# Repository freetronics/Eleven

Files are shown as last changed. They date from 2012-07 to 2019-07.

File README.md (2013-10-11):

Freetronics Eleven R3
=============================
Copyright 2010-2012 Freetronics Pty Ltd  
Freetronics site:  www.freetronics.com  
Freetronics email: info@freetronics.com  

The Eleven is a 100% Arduino Compatible Board, based on the Arduino
Uno reference design, but with improvements and updates for ease of
use, cost and getting started.

Features:

 * Prototyping area
 * LEDs visible on the edge
 * Mini-USB Connector
 * Overlay guide where you need it (both top and bottom)
 * D13 pin works for everything
 * Mounting holes and power pads
 * All connections in the same place

You can view more at our product page at:

  http://www.freetronics.com/eleven

INSTALLATION
------------
The design is saved as an EAGLE project. EAGLE PCB design software is
available from www.cadsoftusa.com free for non-commercial use. To use
this project download it and place the directory containing these files
into the "eagle" directory on your computer. Then open EAGLE and
navigate to Projects -> eagle -> Eleven.

DISTRIBUTION
------------
The specific terms of distribution of this project are governed by the
license referenced below.

LICENSE
-------
This work is licensed under the
Creative Commons Attribution-Share Alike License.  
To view a copy of this license, visit

  http://creativecommons.org/licenses/by-sa/3.0/  
  http://creativecommons.org/licenses/by-sa/3.0/legalcode

or send a letter to

  Creative Commons  
  171 Second Street, Suite 300  
  San Francisco  
  California, 94105  
  USA

The "license" folder within this repository also contains copies of the
licences referenced above.

CREDITS
-------
The Eleven was designed by Marc Alexander (marc@freetronics.com) and
Jonathan Oxer (jon@freetronics.com) inspired by work by the Arduino
team (www.arduino.cc/playground/Main/People) which includes:

 * Massimo Banzi
 * David Cuartielles
 * Tom Igoe
 * Gianluca Martino
 * David A. Mellis

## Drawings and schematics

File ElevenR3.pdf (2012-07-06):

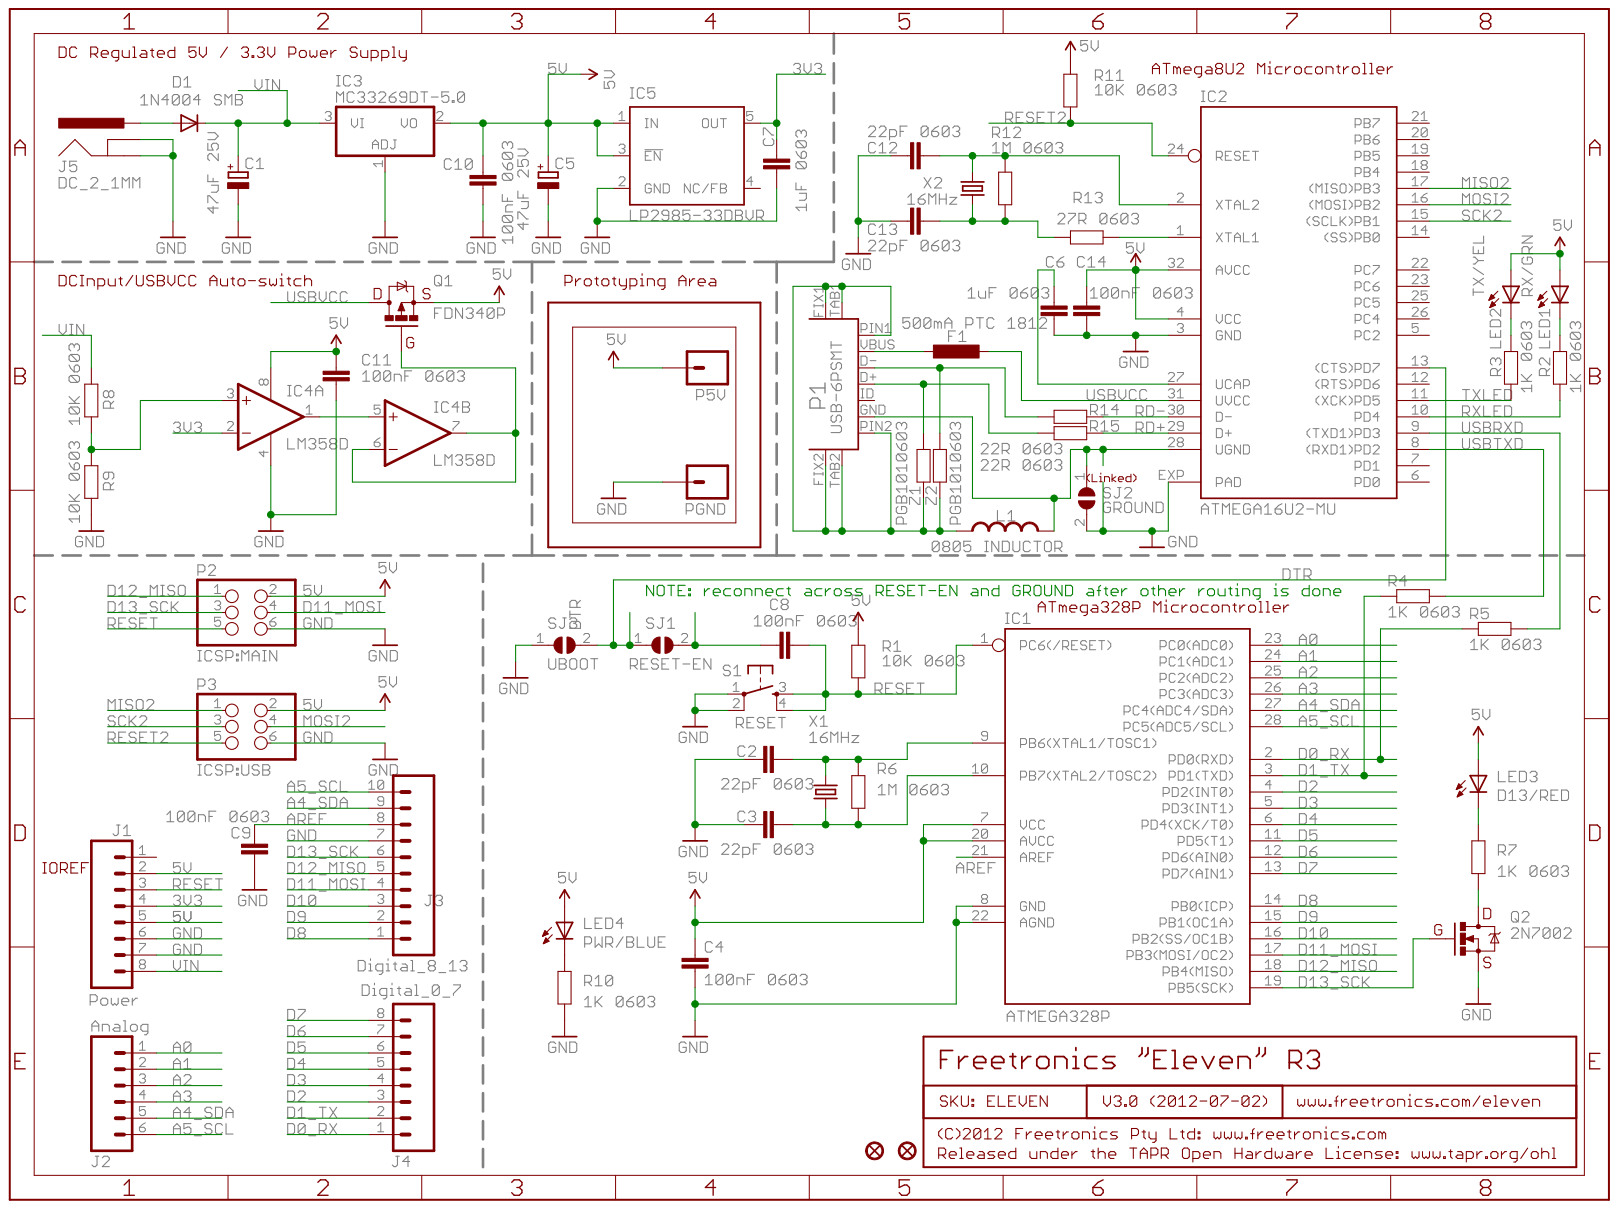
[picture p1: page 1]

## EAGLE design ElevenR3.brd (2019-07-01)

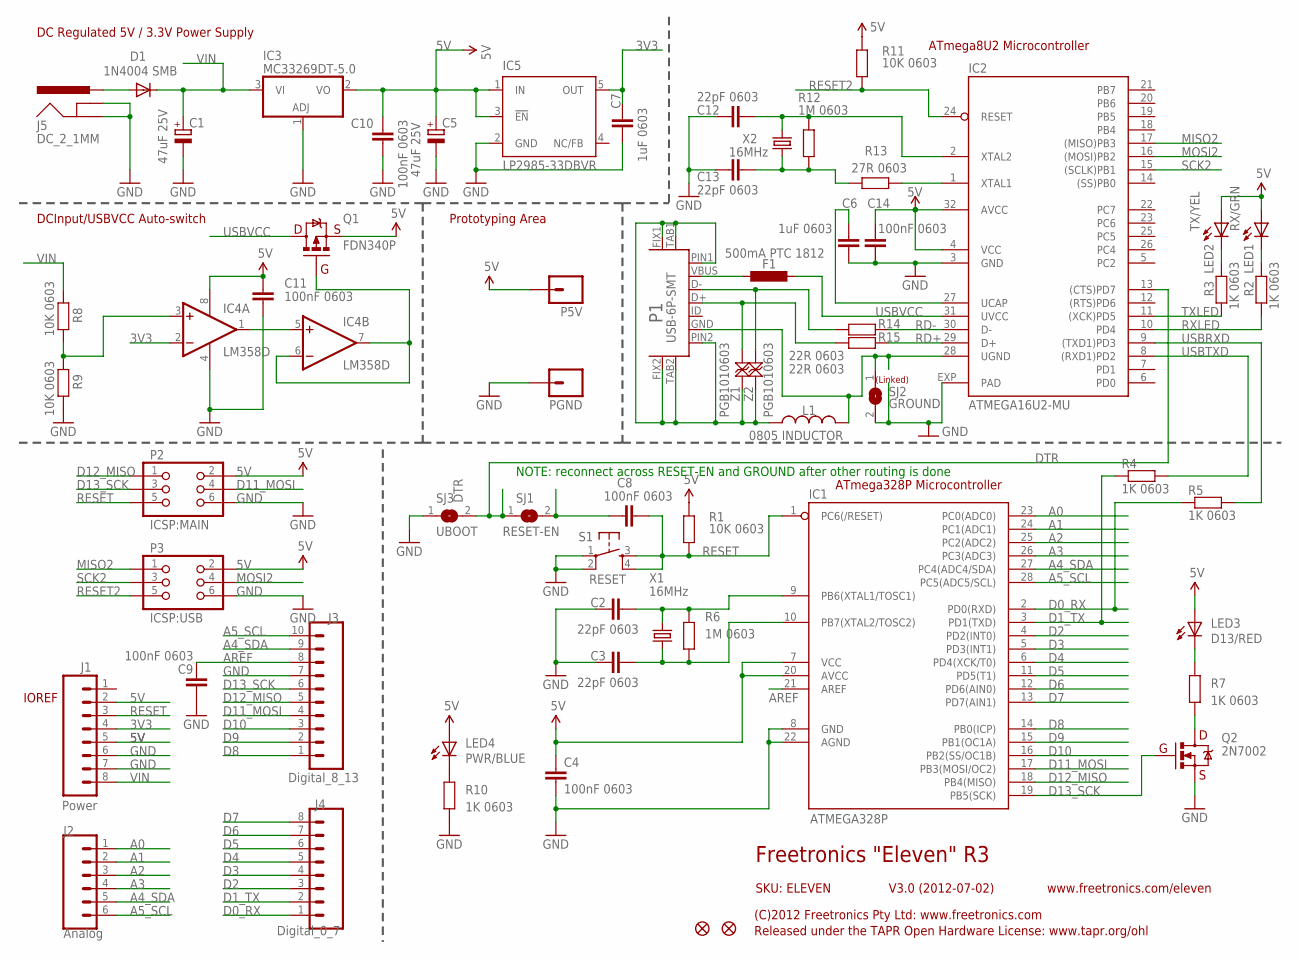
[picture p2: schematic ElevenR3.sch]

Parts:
C1, C5: 47uF 25V; PANASONIC_D
C2, C3, C12, C13: 22pF 0603; C0603
C4, C8, C9, C10, C11, C14: 100nF 0603; C0603
C6, C7: 1uF 0603; C0603
D1: 1N4004 SMB; SMA-DIODE
F1: 500mA PTC 1812; L1812
IC1: ATMEGA328P; DIL28-3
IC2: ATMEGA16U2-MU; ATMEL_QFN32
IC3: MC33269DT-5.0; DPACK
IC4: LM358D; SO08
IC5: LP2985-33DBVR; TEXAS_SOT23-DBV
J1: Power; 1X08-S
J2: Analog; 1X06-S
J3: Digital_8_13; 1X10-S
J4: Digital_0_7; 1X08-S
J5: DC_2_1MM; POWER_JACK_SLOTS
L1: 0805 INDUCTOR; 0805-LARGE
LED1: RX/GRN; LED-0603
LED2: TX/YEL; LED-0603
LED3: D13/RED; LED-0603
LED4: PWR/BLUE; LED-0603
P1: USB-6P-SMT; USB-MICROB-MB05PMXX
P2: ICSP:MAIN; 2X03PTH
P3: ICSP:USB; 2X03PTH
P5V: M01SMD; LUXEON-PAD
PGND: M01SMD; LUXEON-PAD
Q1: FDN340P; SOT23-3
Q2: 2N7002; SOT23-3
R1, R8, R9, R11: 10K 0603; R0603
R2, R3, R4, R5, R7, R10: 1K 0603; R0603
R6, R12: 1M 0603; R0603
R13: 27R 0603; R0603
R14, R15: 22R 0603; R0603
S1: RESET; TACTILE_SMD-6MM
SJ1: RESET-EN; SJ
SJ2: GROUND; SJ
SJ3: UBOOT; SJ
U$5, U$14: FIDUCIAL1X2.5; FIDUCIAL-1X2.5
X1, X2: 16MHz; HC49U-V
Z1, Z2: PGB1010603; TVS0603

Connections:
3V3: C7.2, IC4.2 (-IN), IC5.5 (OUT), J1.4
5V: C4.1, C5.+, C10.1, C11.1, C14.1, IC1.7 (VCC), IC1.20 (AVCC), IC2.4 (VCC), IC2.32 (AVCC), IC3.2 (VO), IC4.8 (V+), IC5.1 (IN), IC5.3 (!EN), J1.2, J1.5, LED1.A, LED2.A, LED3.A, LED4.A, P2.2, P3.2, P5V.P$1, Q1.2 (S), R1.2, R11.2
A0: IC1.23 (PC0(ADC0)), J2.1
A1: IC1.24 (PC1(ADC1)), J2.2
A2: IC1.25 (PC2(ADC2)), J2.3
A3: IC1.26 (PC3(ADC3)), J2.4
A4_SDA: IC1.27 (PC4(ADC4/SDA)), J2.5, J3.9
A5_SCL: IC1.28 (PC5(ADC5/SCL)), J2.6, J3.10
AREF: C9.1, IC1.21 (AREF), J3.8
D0_RX: IC1.2 (PD0(RXD)), J4.1, R5.1
D1_TX: IC1.3 (PD1(TXD)), J4.2, R4.1
D2: IC1.4 (PD2(INT0)), J4.3
D3: IC1.5 (PD3(INT1)), J4.4
D4: IC1.6 (PD4(XCK/T0)), J4.5
D5: IC1.11 (PD5(T1)), J4.6
D6: IC1.12 (PD6(AIN0)), J4.7
D7: IC1.13 (PD7(AIN1)), J4.8
D8: IC1.14 (PB0(ICP)), J3.1
D9: IC1.15 (PB1(OC1A)), J3.2
D10: IC1.16 (PB2(SS/OC1B)), J3.3
D11_MOSI: IC1.17 (PB3(MOSI/OC2)), J3.4, P2.4
D12_MISO: IC1.18 (PB4(MISO)), J3.5, P2.1
D13_SCK: IC1.19 (PB5(SCK)), J3.6, P2.3, Q2.1 (G)
DTR: IC2.13 ((CTS)PD7), SJ1.1, SJ3.2
GND: C1.-, C2.1, C3.1, C4.2, C5.-, C6.2, C7.1, C9.2, C10.2, C11.2, C12.1, C13.1, C14.2, IC1.8 (GND), IC1.22 (AGND), IC2.3 (GND), IC2.EXP (PAD), IC3.1 (ADJ), IC4.4 (V-), IC5.2 (GND), J1.6, J1.7, J3.7, J5.GND, J5.GNDBREAK, P2.6, P3.6, PGND.P$1, Q2.2 (S), R9.1, R10.1, S1.1, S1.2, SJ2.2, SJ3.1
MISO2: IC2.17 ((MISO)PB3), P3.1
MOSI2: IC2.16 ((MOSI)PB2), P3.4
unnamed: C8.1, SJ1.2
unnamed: IC2.1 (XTAL1), R13.1
unnamed: L1.1, P1.FIX1, P1.FIX2, P1.PIN1, P1.PIN2, P1.TAB1, P1.TAB2, Z1.2, Z2.2
unnamed: LED3.C, R7.2
unnamed: C2.2, IC1.9 (PB6(XTAL1/TOSC1)), R6.2, X1.2
unnamed: Q2.3 (D), R7.1
unnamed: C3.2, IC1.10 (PB7(XTAL2/TOSC2)), R6.1, X1.1
unnamed: D1.A, J5.PWR
unnamed: IC4.3 (+IN), R8.1, R9.2
unnamed: IC4.1 (OUT), IC4.5 (+IN)
unnamed: LED1.C, R2.2
unnamed: IC4.6 (-IN), IC4.7 (OUT), Q1.1 (G)
unnamed: LED2.C, R3.2
unnamed: LED4.C, R10.2
unnamed: P1.D+, R15.2, Z1.1
unnamed: P1.D-, R14.2, Z2.1
unnamed: C12.2, IC2.2 (XTAL2), R12.2, X2.2
unnamed: C13.2, R12.1, R13.2, X2.1
unnamed: F1.1, P1.VBUS
unnamed: C6.1, IC2.27 (UCAP)
RD+: IC2.29 (D+), R15.1
RD-: IC2.30 (D-), R14.1
RESET: C8.2, IC1.1 (PC6(/RESET)), J1.3, P2.5, R1.1, S1.3, S1.4
RESET2: IC2.24 (RESET), P3.5, R11.1
RXLED: IC2.10 (PD4), R2.1
SCK2: IC2.15 ((SCLK)PB1), P3.3
TXLED: IC2.11 ((XCK)PD5), R3.1
UGND: IC2.28 (UGND), L1.2, P1.GND, SJ2.1
USBRXD: IC2.9 ((TXD1)PD3), R5.2
USBTXD: IC2.8 ((RXD1)PD2), R4.2
USBVCC: F1.2, IC2.31 (UVCC), Q1.3 (D)
VIN: C1.+, D1.C, IC3.3 (VI), J1.8, R8.2

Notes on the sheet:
Prototyping Area
DCInput/USBVCC Auto-switch
DC Regulated 5V / 3.3V Power Supply
ATmega328P Microcontroller
ATmega8U2 Microcontroller
NOTE: reconnect across RESET-EN and GROUND after other routing is done
Freetronics "Eleven" R3
V3.0 (2012-07-02)
SKU: ELEVEN
(C)2012 Freetronics Pty Ltd: www.freetronics.com
Released under the TAPR Open Hardware License: www.tapr.org/ohl
www.freetronics.com/eleven
(Linked)
IOREF

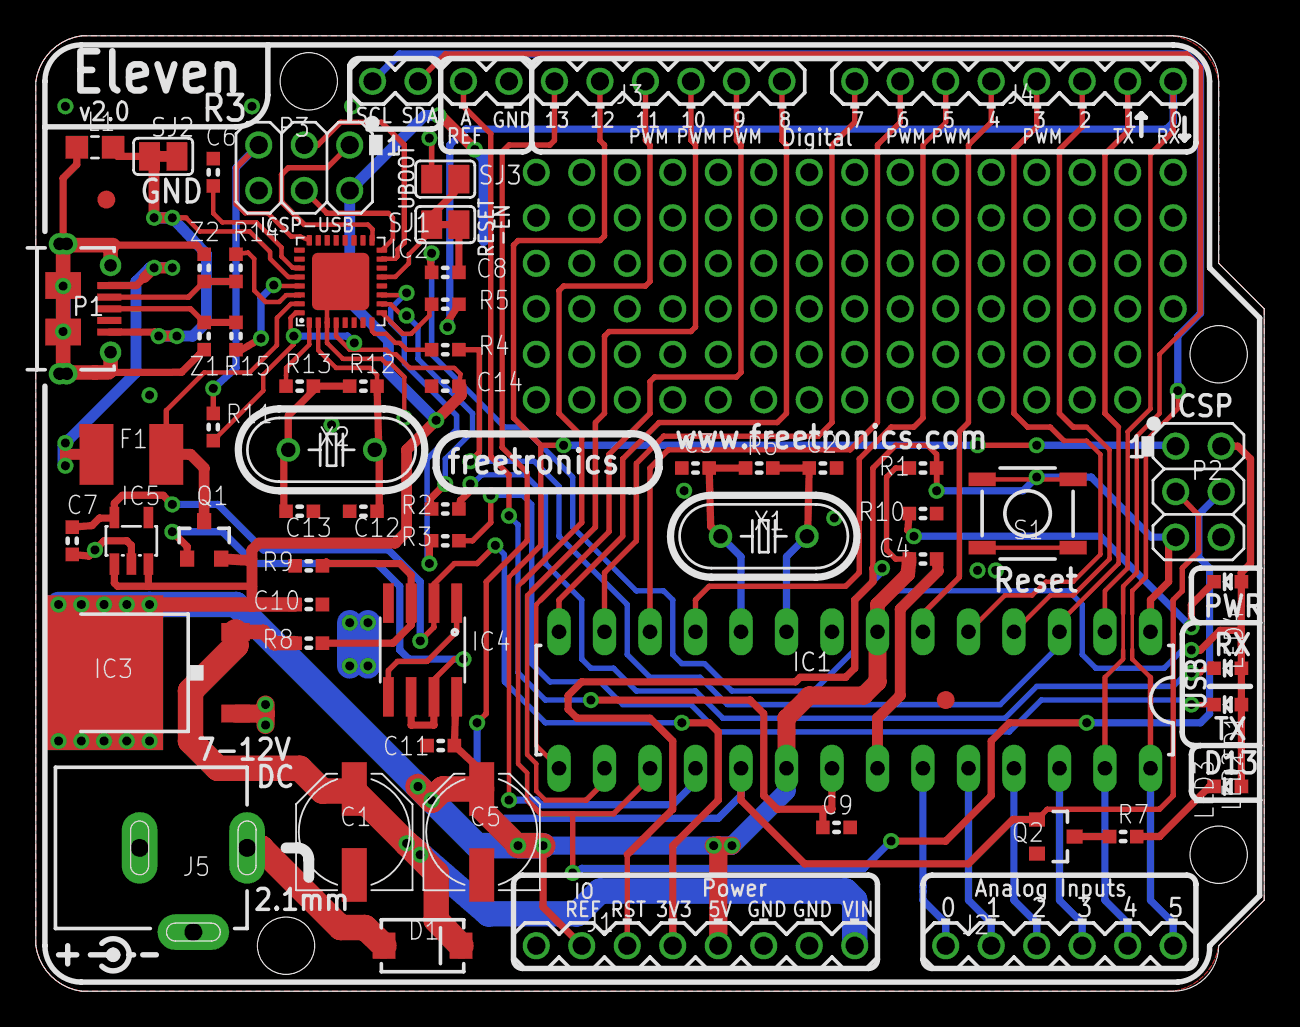
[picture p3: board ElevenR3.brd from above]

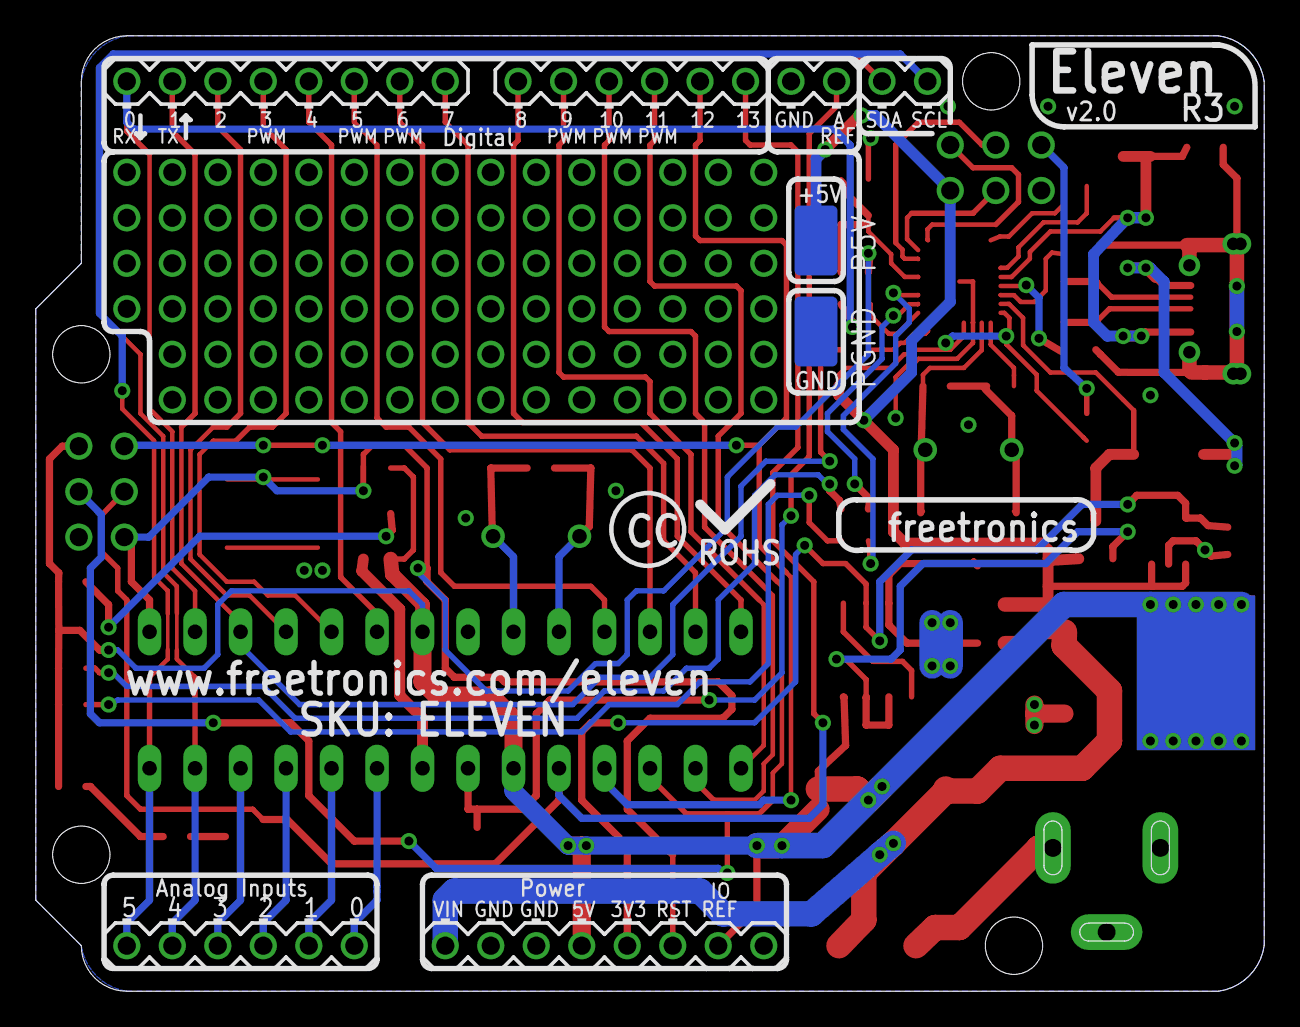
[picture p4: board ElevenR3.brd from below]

Board: 2 copper layers, 68.6 x 53.3 mm, 63 parts (2 on the bottom side), 59 nets.

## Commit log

2010-11-20 Imported project
    [Eleven.brd, Eleven.sch]
2010-11-21 Isolated USB GND from signal GND; fixed value of USB D series resistors
    [Eleven.sch]
2010-11-21 Started moving 8U2 and associated parts into position
    [Eleven.brd]
2010-11-21 Minor parts shuffling
    [Eleven.brd]
2010-11-21 Removed link across RESET-EN to help airwires go to the right place until routing is done
    [Eleven.sch]
2010-11-21 Removed C11; changed LED resistor values; separated headers on schematic
    [Eleven.brd, Eleven.sch]
2011-01-03 Pre-release - last lookover
    [Eleven.brd, Eleven.sch]
2011-01-03 Tweaks - designator layer
    [Eleven.brd, Eleven.sch]
2011-01-05 Final - pre-inspection
    [Eleven.brd, Eleven.sch]
2011-01-05 SKU on sch page, pdf recreated
    [Eleven.sch]
2012-06-24 Beginning of conversion to R3
    [Eleven.brd, Eleven.sch]
2012-06-24 Renamed project files
    [ElevenR3.brd, ElevenR3.sch]
2012-06-26 Routed I2C and converted to microUSB
    [ElevenR3.brd, ElevenR3.sch]
2012-07-03 Overlay, layout, and schematic tweaks
    [ElevenR3.brd, ElevenR3.sch]
2012-07-03 Routing, position, and overlay tweaks
    [ElevenR3.brd]
2012-07-05 Replaced uUSB footprint
    [ElevenR3.brd, ElevenR3.sch]
2012-07-06 R3 updates
    [ElevenR3.brd]
2012-07-06 Production release v2.0 after small revisions
    [ElevenR3.brd, ElevenR3.sch]
2019-07-01 Replaced most parts using SuperHouse library to add 3D models
    [ElevenR3.brd, ElevenR3.sch]
